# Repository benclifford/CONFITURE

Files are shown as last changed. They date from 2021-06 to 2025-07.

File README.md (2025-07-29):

# CONFITURE

A co-routine based executive for a NeoPixel jamjar,
running on a Pi Pico (RP2040).

## Dramatis Personae

* A jam jar, jam eaten, jar de-labelled and washed
* Pi Pico (original)
* NeoPixel LED string (I blew up the first pixel, so I've cut it off)
* Adafruit CircuitPython 9.2.8
* Rotary encoder with push button

## Confiture v3 board

In kicad-test directory.

Fabricated x3 by aisler.

This works.

Problems to fix if I make v4:

i) the mounting holes for USB connector are too small, so the connector
rides a bit high and is not as securely connected as I want.

ii) There is no facility for protective capacitor and resistor. This is
fine for small battery powered projects, but it would be nice to have
the option to add: for capacitor, this could be entirely optional points
across the power bus. For the resistor, probably ok to make it compulsory
with an option to use a direct link not a resistor when placing components.

iii) v. minor some of the writing is off the side of the board or
hidden by components. This could all be tidied up.

iv) add cable tie strain relief hole

## minicom

To talk to micropython:

minicom --device=/dev/ttyACM0 --baud=115200

then press ctrl-C to interrupt and get a python prompt -- otherwise it
sits there with no output as it runs the LEDs.

## third party drivers

neopixel.py in this repo is neopixel.py from
0ba2f2122a54a71b1bc3576f87b1ba7dfc9db11e of 
https://github.com/adafruit/Adafruit_CircuitPython_NeoPixel/

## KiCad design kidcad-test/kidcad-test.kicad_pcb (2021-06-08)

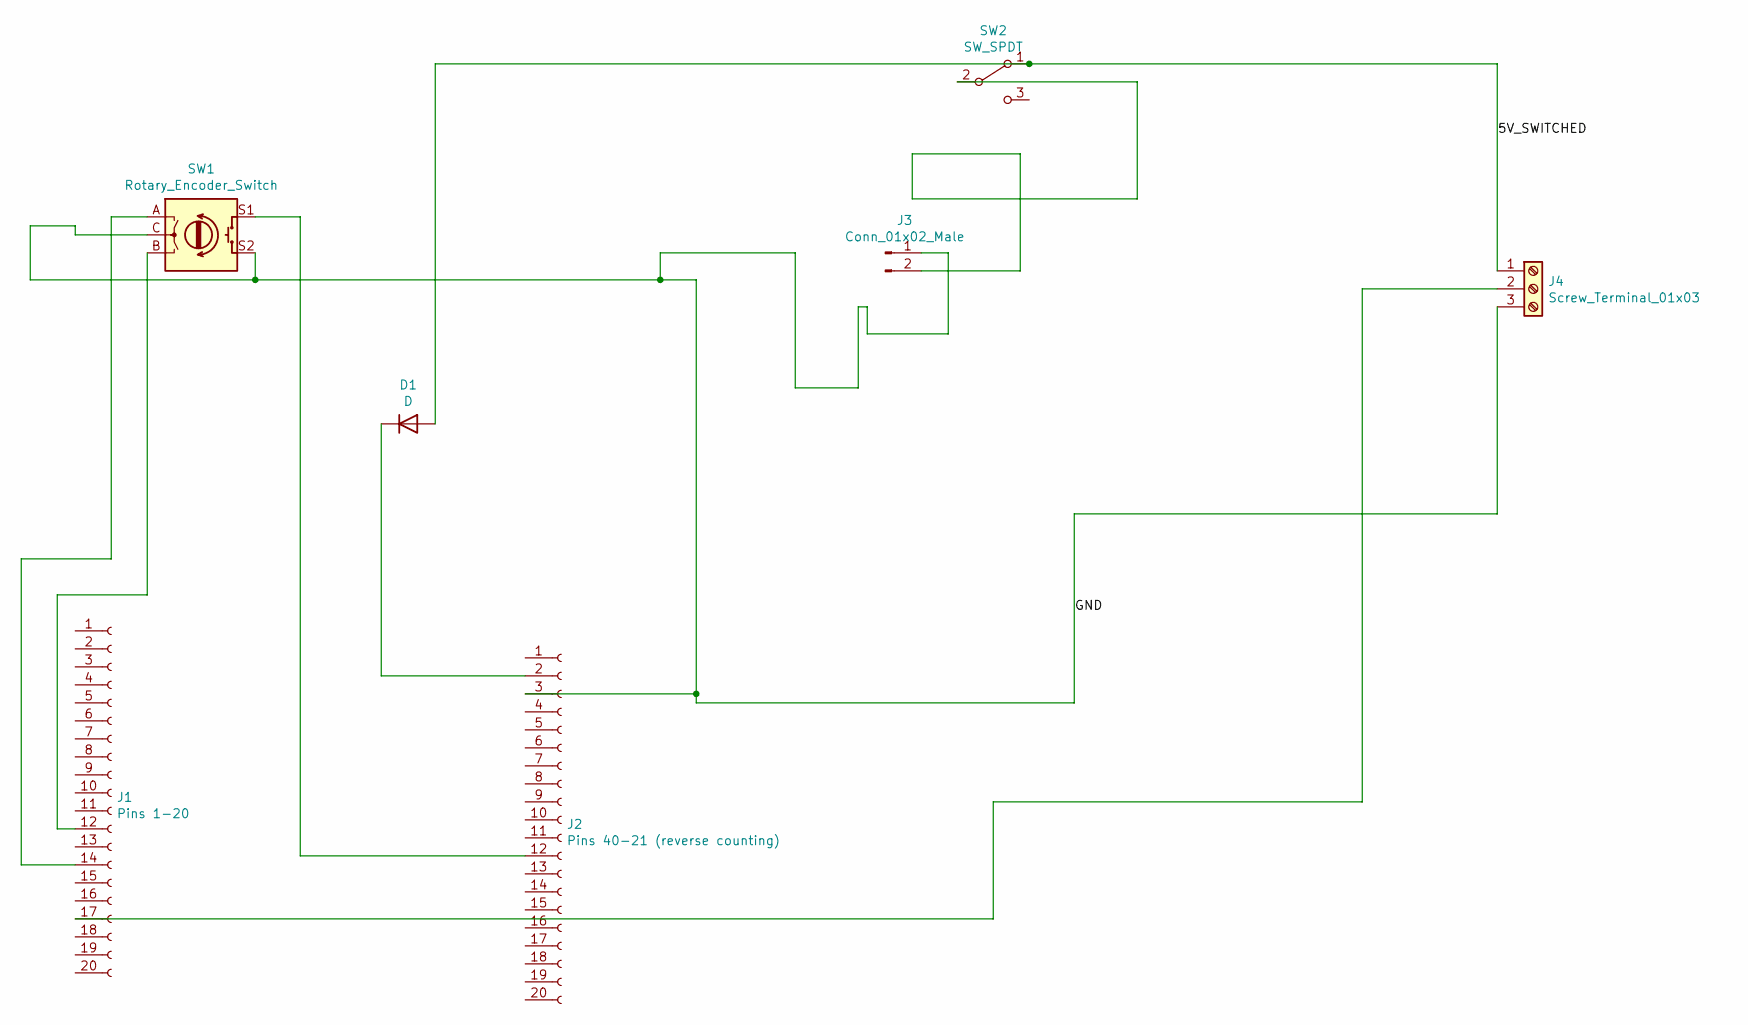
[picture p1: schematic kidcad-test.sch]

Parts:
D1: D; D_DO-41_SOD81_P10.16mm_Horizontal
J1: Pins 1-20; PinHeader_1x20_P2.54mm_Vertical
J2: Pins 40-21 (reverse counting); PinHeader_1x20_P2.54mm_Vertical
J3: Conn_01x02_Male; usb_micro_b_power_pp_benc
J4: Screw_Terminal_01x03; PinHeader_1x03_P2.54mm_Vertical
SW1: Rotary_Encoder_Switch; RotaryEncoder_Alps_EC11E-Switch_Vertical_H20mm
SW2: SW_SPDT; PinHeader_1x03_P2.54mm_Vertical

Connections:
/5V_SWITCHED: D1.2 (A), J4.1, SW2.1 (A)
/GND: J2.3, J3.1, J4.3, SW1.C, SW1.S2
unnamed: D1.1 (K), J2.2
unnamed: J1.12, SW1.B
unnamed: J1.14, SW1.A
unnamed: J1.17, J4.2
unnamed: J2.12, SW1.S1
unnamed: J3.2, SW2.2 (B)

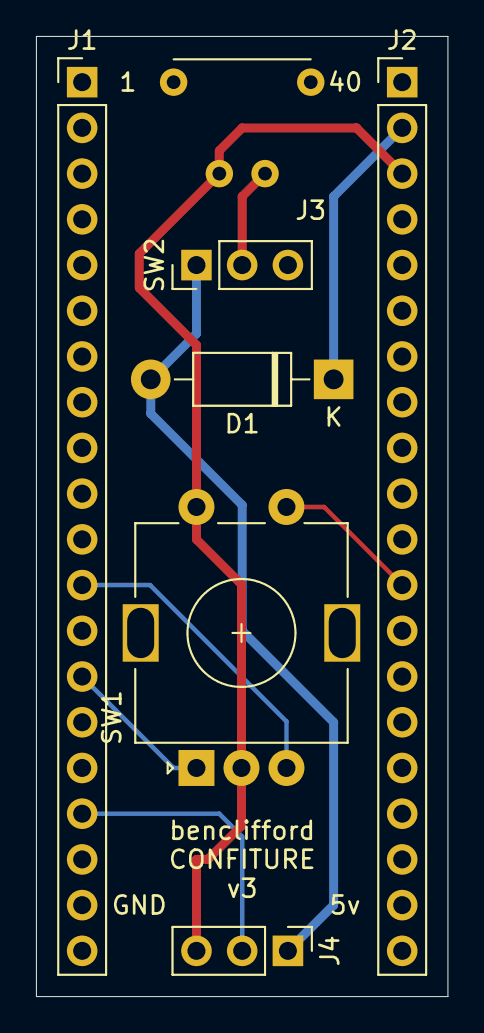
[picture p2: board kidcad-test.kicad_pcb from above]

Board: 2 copper layers, 22.9 x 53.3 mm, 7 parts (0 on the bottom side), 8 nets.

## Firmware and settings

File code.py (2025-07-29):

import board
import rotaryio
import digitalio

import random
import time

import jar

from helpers import partial

print("CONFITURE: jam jar executive")

rotary_encoder = rotaryio.IncrementalEncoder(board.GP21, board.GP22)

rotary_button = digitalio.DigitalInOut(board.GP9)
rotary_button.switch_to_input(pull = digitalio.Pull.UP)


def partial_by_range(func, start, end, step):
  l = []
  v = start
  while v < end:
    l.append(partial(func, v))
    v += step
  return l


static_modes = [jar.rgb1,
               jar.static_random,
               jar.static_saturated_random,
               jar.static_saturated_rainbow,
               jar.nightlight] + \
               partial_by_range(jar.solid_saturated, 0, 1, 0.04) + \
               partial_by_range(jar.static_white_dither, 0.1, 1, 0.1) + \
               partial_by_range(jar.static_saturated_magnified_rainbow, 0, 1, 0.05) + \
               partial_by_range(jar.contrasts, 0, 0.5, 0.05)


dynamic_modes = [jar.pixphase1, jar.huespin6, jar.huespin5, jar.huespin4, jar.huespin3, jar.huespin2, jar.rainbow1, jar.drip1, jar.huespin1, jar.centre1, jar.vert1, jar.vert2, jar.threepart1, jar.primaryswitcher1, jar.phase4, jar.primaryswitcher2, jar.contr2, jar.phase1, jar.fountain1, jar.contr3,
  partial(jar.firefly, jar.firefly_rainbow),
  partial(jar.firefly, jar.firefly_blue_blip),
  partial(jar.firefly, jar.firefly_orange_pulse),
  partial(jar.firefly, jar.firefly_green_red)

  ]

def main_driver():
  n = 0

  modeset = True  # True/False to represent dynamic/static modes
  current_modeset = modeset

  autochange = time.time()

  if modeset:
    mode_list = dynamic_modes
  else:
    mode_list = static_modes

  current_mode = mode_list[0]()
  current_mode_pos = 0

  while True:
    if not rotary_button.value:
      modeset = not modeset
      if modeset:
        print("enabling autochange due to entering dynamic mode")
        autochange = time.time() # turn on autochange if going into dynamic mode
      else:
        print("disabling autochange due to entering static mode")
        autochange = None
      time.sleep(0.1)

    if rotary_encoder.position != current_mode_pos or current_modeset != modeset:
      if rotary_encoder.position != current_mode_pos:
        autochange = None  # turn off autochange if a (dynamic) mode is manually selected
        print("disabling autochange due to manual change")

      current_mode_pos = rotary_encoder.position

      if modeset:
        mode_list = dynamic_modes
      else:
        mode_list = static_modes

      current_modeset = modeset

      new_mode = current_mode_pos % len(mode_list)
      print(f"New mode {new_mode}")
      current_mode = mode_list[new_mode]()

    elif autochange is not None and (autochange + 60) < time.time():
      autochange = time.time()
      print("Updating autochange time on mode change")
 
      if modeset:
        mode_list = dynamic_modes
      else:
        mode_list = static_modes

      current_modeset = modeset

      new_mode = random.randint(0, len(mode_list) - 1)
      print(f"New autochange mode {new_mode}")
      current_mode = mode_list[new_mode]()

   

    v = current_mode.__next__()

    if v:
      time.sleep(v)

    n += 1

if __name__ == "__main__":
  main_driver()

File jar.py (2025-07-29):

import neopixel
import board
import random
import time
import math

import configuration

pixels = neopixel.NeoPixel(configuration.neopixel_pin, configuration.num_leds, auto_write=False)

tau = math.pi * 2.0

def nightlight():
  for n in range(0, configuration.num_leds):
    pixels[n] = (1,0,0)

  while True:
    pixels.show()
    yield 0.1


def contrasts(phase):
  tri = tau / 3.0
  p_phase = phase * tau
  p2_phase = (phase + 0.5) * tau
  r = norm(math.sin(p_phase + tri))
  g = norm(math.sin(p_phase - tri))
  b = norm(math.sin(p_phase))

  r2 = norm(math.sin(p2_phase + tri))
  g2 = norm(math.sin(p2_phase - tri))
  b2 = norm(math.sin(p2_phase))

  for n in range(0, configuration.num_leds):
    if n % 2 == 0:
      pixels[n] = (r,g,b)
    else:
      pixels[n] = (r2,g2,b2)

  while True:
    pixels.show()
    yield 0.1



def solid_saturated(phase):
  tri = tau / 3.0
  p_phase = phase * tau
  r = norm(math.sin(p_phase + tri))
  g = norm(math.sin(p_phase - tri))
  b = norm(math.sin(p_phase))

  
  for n in range(0, configuration.num_leds):
    pixels[n] = (r,g,b)

  while True:
    pixels.show()
    yield 0.1

def static_random():
  for n in range(0, configuration.num_leds):
    r = norm2(2.0 * random.random())
    g = norm2(2.0 * random.random())
    b = norm2(2.0 * random.random())
    pixels[n] = (r,g,b)
  while True:
    pixels.show()
    yield 0.1

def static_saturated_random():
  for n in range(0, configuration.num_leds):
    tri = tau / 3.0
    p_phase = random.random() * tau
    r = norm(math.sin(p_phase + tri))
    g = norm(math.sin(p_phase - tri))
    b = norm(math.sin(p_phase))
    pixels[n] = (r,g,b)
  while True:
    pixels.show()
    yield 0.1

def static_saturated_rainbow():
  for n in range(0, configuration.num_leds):
    tri = tau / 3.0
    frac = float(n) / float(configuration.num_leds)
    p_phase = frac * tau
    r = norm(math.sin(p_phase + tri))
    g = norm(math.sin(p_phase - tri))
    b = norm(math.sin(p_phase))
    pixels[n] = (r,g,b)
  while True:
    pixels.show()
    yield 0.1


def static_saturated_magnified_rainbow(p_off):

  for n in range(0, configuration.num_leds):
    tri = tau / 3.0
    frac = float(n) / float(configuration.num_leds)
    p_phase = (frac / 3.0 + p_off) * tau
    r = norm(math.sin(p_phase + tri))
    g = norm(math.sin(p_phase - tri))
    b = norm(math.sin(p_phase))
    pixels[n] = (r,g,b)
  while True:
    pixels.show()
    yield 0.1



def static_white_dither(frac):
  pixels.fill( (0,0,0) )

  intensity = 0.0

  for p in range(0, configuration.num_leds):
    intensity = intensity + frac

    if intensity > 0.5:
      pixels[p] = (255,255,255)
      intensity = intensity - 1.0

  while True:
    pixels.show()
    yield 0.1


def pixphase1():
  phases = [0] * configuration.num_leds 
  phase_shifts = [0.01] * configuration.num_leds
  for n in range(0,configuration.num_leds):
    phases[n] = random.random()
    phase_shifts[n] += random.random() * 0.01

  while True:
    for n in range(0, configuration.num_leds):
      p_phase = phases[n] * tau
      r = norm(math.sin(p_phase))
      g = int(  0.3 * norm(     math.sin(p_phase)   ))
      b = 0
      pixels[n] = (r, g, b)

      phases[n] = (phases[n] + phase_shifts[n]) % 1.0
    pixels.show()
    yield 0.02
     


def rainbow1():

  base = 0
  while True:
    for n in range(0,configuration.num_leds):
      v = 1 + (base + n) % 6 # cycle through 1..6
      if v & 1 == 0:
        r = 255
      else:
        r = 0
      if v & 2 == 0:
        g = 255
      else:
        g = 0
      if v & 4 == 0:
        b = 255
      else:
        b = 0
      pixels[n] = (r, g, b)
    pixels.show()
    base = (base + 1) % 6
    yield 0.1
    


def drip1():
  pixels.fill( (0,0,0) )

  hue = random.random()

  while True:

    rgb = hue_saturated(hue)
    contr_rgb = hue_saturated((hue + 0.3) % 1.0)

    for n in range(0, 3):
      pixels[n] = rgb
    
    for n in range(46, configuration.num_leds):
      pixels[n] = rgb

    pixels.show()

    # TODO: interruptible sleep
    for n in range(0,9):
      yield 0.1

    for n in range(3,46):
      pixels[n] = contr_rgb
      pixels.show()
      yield 0.01
      pixels[n] = (0,0,0)
      pixels.show()


def huespin1():
  hue = random.random()
  while True:
    rgb = hue_saturated(hue)
    pixels.fill(rgb)
    pixels.show()

    hue = (hue + 0.03) % 1.0
    yield 0.03


def huespin2():
  pixels.fill( (0,0,0) )
  hue = random.random()
  while True:
    n = random.randint(0, configuration.num_leds - 1)
    rgb = hue_saturated((hue + random.random() * 0.3) % 1.0)
    pixels[n] = rgb
    pixels.show()
    pixels[n] = (0,0,0)
    yield 0.01

    hue = (hue + 0.001) % 1.0


def huespin3():
  print("huespin3")
  pixels.fill( (0,0,0) )
  hue = random.random()
  while True:

    for n in range(0,configuration.num_leds):
      (r,g,b) = pixels[n]
      pixels[n] = (r * 2/3, g * 2/3, b * 2/3)

    n = random.randint(0,configuration.num_leds - 1)
    rgb = hue_saturated((hue + random.random() * 0.3) % 1.0)
    pixels[n] = rgb
    pixels.show()
    # pixels[n] = (0,0,0)
    yield 0.1

    hue = (hue + 0.01) % 1.0


def huespin4():
  hue = random.random()
  while True:
    hue = (hue + 0.2 + random.random() * 0.5)
    for brightness in range(0,10):
        rgb = hue_saturated(hue, v=brightness/10.0)
        pixels.fill(rgb)
        pixels.show()
        yield 0.03
    for brightness in range(10,-1,-1):
        rgb = hue_saturated(hue, v=brightness/10.0)
        pixels.fill(rgb)
        pixels.show()
        yield 0.03

    for n in range(0,9):
      yield 0.1


def huespin5():
  hue = random.random()
  while True:
    hue = (hue + 0.2 + random.random() * 0.5)
    for brightness in range(0,10):
        rgb = hue_saturated2(hue, v = brightness / 10.0)
        pixels.fill(rgb)
        pixels.show()
        yield 0.03
    for brightness in range(10,-1,-1):
        rgb = hue_saturated2(hue, v = brightness / 10.0)
        pixels.fill(rgb)
        pixels.show()
        yield 0.03

    for n in range(0,9):
      yield 0.1


def huespin5():
  hue = random.random()
  while True:
    hue = (hue + 0.2 + random.random() * 0.5)
    rgb = hue_saturated2(hue)
    for n in range(0,configuration.num_leds):
        pixels[n] = rgb
        pixels.show()
        yield 0.03
    for brightness in range(10,-1,-1):
        rgb = hue_saturated2(hue, v = brightness / 10.0)
        pixels.fill(rgb)
        pixels.show()
        yield 0.03

    yield


def huespin6():
  hue = random.random()
  while True:
    for n in range(0,configuration.num_leds):
      rgb = hue_saturated2(hue + random.random() * 0.25, v = random.random() * 0.5 + 0.5)
      pixels[n] = rgb
    pixels.show()

    hue = (hue + 0.05) % 1.0
    yield 0.05
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

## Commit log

2021-03-27 Import hacking from board
2021-03-27 Add jam jar to bill of materials
2021-03-27 Basic supervisor that toggles between two modes using rotary encoder
2021-04-04 Move neopixels to a pin more convenient for protoboard
2021-04-04 Move rotary encoders to pins more convenient for permaproto: further down board, and either side of a GND
2021-04-05 Move rotary encoder even further down the board
2021-04-05 Add input for the rotary encoder button for testing at REPL
2021-06-06 reconfigure to 2nd board (different pin, 1 more LED)
2021-06-06 Add configuration file for LED pin and number of LEDs
2021-06-06 Switch to yield-based effects for delays, to potentially allow faster mode change implementation
2021-06-06 Replace every-n with fraction/dither based that has a slightly more interesting pattern
    [code.py, jar.py]
2021-06-06 Replace solid modes with saturated-by-hue modes for same effect but better progammability
    [code.py, jar.py]
2021-06-06 Replace explicitly enumerated partial applications with procedurally generated list
    [code.py]
2021-06-06 Add rainbow over 1/3rd of colour wheel, adjustable static mode
2021-06-07 replace hardcoded 48s with num_leds - 1 to accomodate 50 LED string
    [jar.py]
2021-06-07 Swap long pause effect for several shorter ones to allow event polling to happen faster
    [jar.py]
2021-06-08 Add all kicad files
    [kidcad-test.kicad_pcb, kidcad-test.sch]
2021-07-06 Add board v3 comments
2021-07-06 Update board v3 notes
2025-07-29 As imported from actual working board in July 2025, which has had non-version-controlled hacking on it
2025-07-29 configuration as actually used on mirella's board for the last few years - different pin, and one less LED due to breakage
2025-07-29 Upgrade CircuitPython and consequential needed neopixel.py upgrade from vendor. works on mirellas (broken rotary encoder) board
2025-07-29 clarify using original pi pico, because i'm beginning to experiment with pico w and pico 2 w too
2025-07-29 Rotary encoder pins as used on confiture v3 board (flipped from what was in repo)
    [code.py]
